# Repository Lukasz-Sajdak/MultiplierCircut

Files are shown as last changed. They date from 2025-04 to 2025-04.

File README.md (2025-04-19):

# Multiplier Circuit

## Overview
Analog multiplier circuit designed to perform multiplication of two input signals by utilizing various functional blocks working in tandem. The circuit uses customized components for efficient operation and to meet specific design requirements.

schemat

## Main Functional Blocks
The schematic is divided into the following key sections:

### Power Supply
- **Purpose:** Voltage stabilization for the circuit.
- **Components:**
  - **V+ Regulation:** The circuit uses a standard power supply for V+.
  - **V- Generation:** The negative voltage is generated using the **ICL7660AIBAZA** charge pump.

### Charge Pump
- **Purpose:** Generates the negative voltage required for specific circuit components.

### Voltage-Frequency Converter
- **Purpose:** This block, based on the **LM331**, controls and filters the input signal.
- **Adjustment:** The signal can be adjusted using an **R3 potentiometer** for finer control over the frequency.
- **Issue:** The V/F Converter isn't operating as expected due to incorrect resistor choices and insufficient current flowing into the IC.

### Adding Offset
- **Purpose:** Adds a frequency shift to the input signal, ensuring correct operation when dealing with a 0V input.
- **Components:** Implemented with the **TS912** operational amplifier.

### Subtracting Offset
- **Purpose:** Compensates for any voltage offset by subtracting a specific value.
- **Components:** The **TS912** operational amplifier is used here as well, with the offset adjusted via the **R18 potentiometer**.

### Voltage Reference
- **Purpose:** Provides a reference voltage for the circuit.
- **Component:** **TL431BIDBZR** is used for this purpose.

### Analog Switch
- **Component:** **DG419DY**  
- **Purpose:** Transfers charge based on V/F signal to perform multiplication with Vy. Connected to capacitor and output stage.

## How It Works

The circuit receives two input signals: **Vx** and **Vy**, and performs an analog multiplication of these signals.

The **Vx** signal is fed into a voltage-to-frequency converter (**V/F**, based on LM331), which converts the voltage into a frequency proportional to **Vx**. This frequency output is then used to control an analog switch.

The analog switch operates by transferring charge from the **Vy** signal to a capacitor in response to the frequency generated by the V/F converter.

**Switch connections:**
- **IN** — control signal from V/F (frequency depends on **Vx**)  
- **S2** — voltage input **Vy**  
- **D** — capacitor  
- **S1** — output  

As a result, the amount of transferred charge—and thus the output voltage—depends on both the **Vy** amplitude and the frequency determined by **Vx**. This results in **analog multiplication** of **Vx** and **Vy**.

## Known Issues
- The **V/F** is not functioning correctly due to improper resistor selection and insufficient current flow to the integrated circuit. This needs to be addressed for proper operation.

## PCB Design
The physical implementation of the circuit has been designed using **KiCad EDA 8.0.2** software.

The circuit has been **soldered and assembled**.

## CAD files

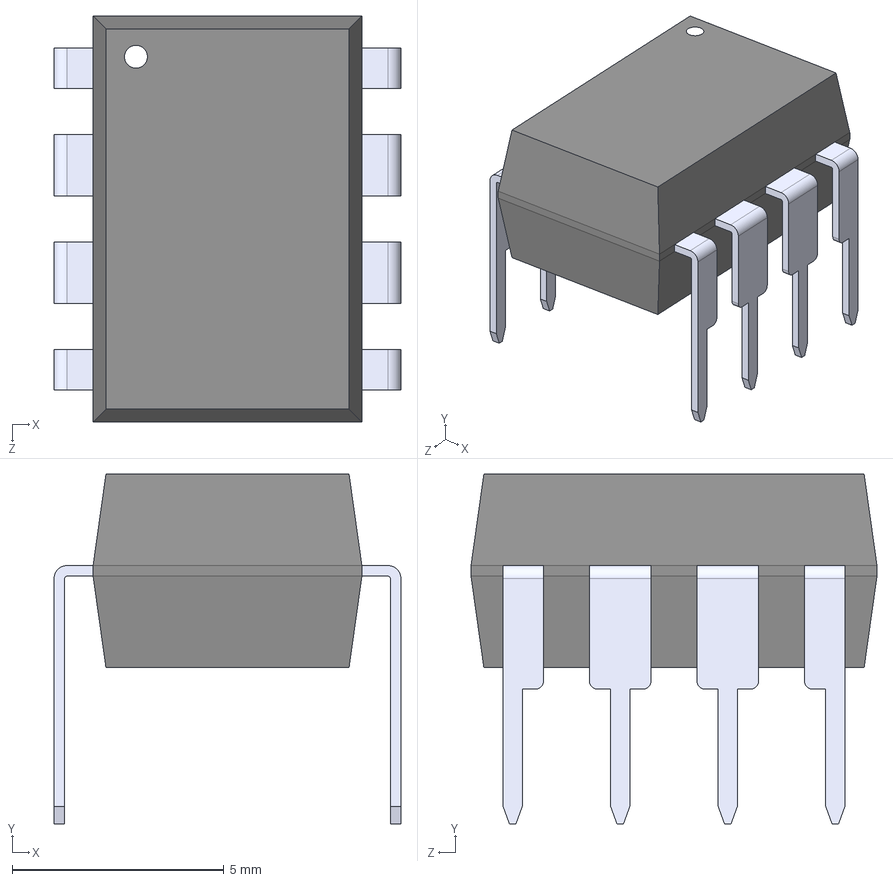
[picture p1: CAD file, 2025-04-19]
LM331N_NOPB/LM331N_NOPB.step
8.19 x 8.26 x 9.59 mm

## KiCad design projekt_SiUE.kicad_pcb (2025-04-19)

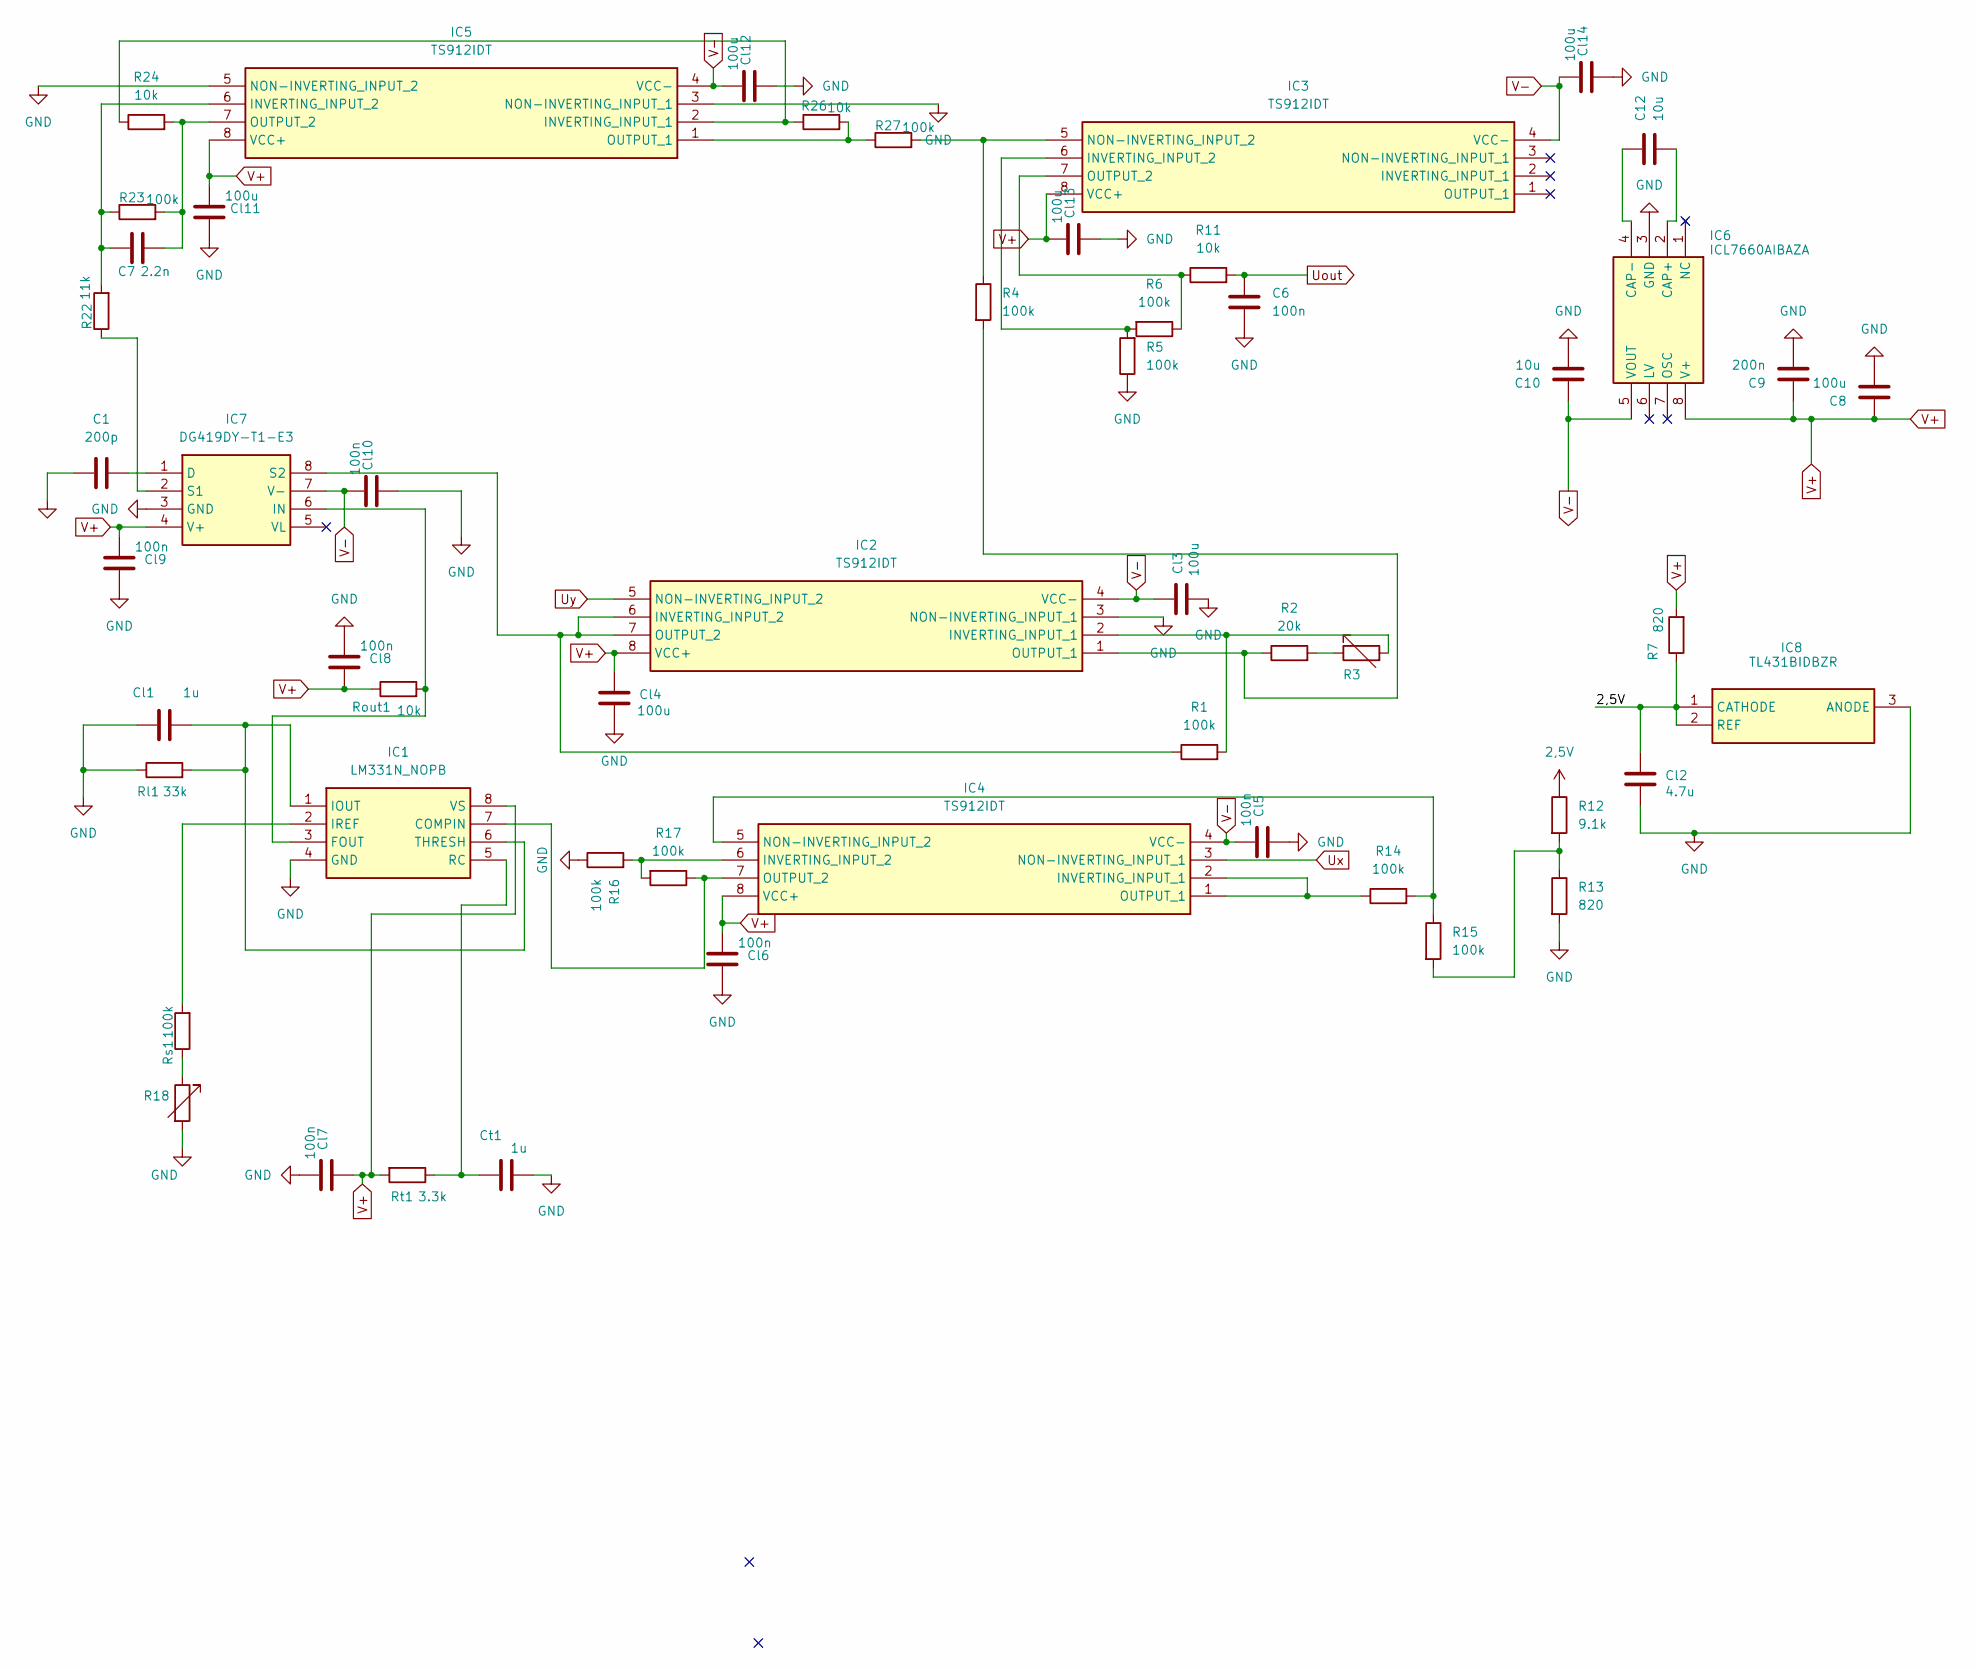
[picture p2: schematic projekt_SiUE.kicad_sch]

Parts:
C1: 200p; C_0805_2012Metric_Pad1.18x1.45mm_HandSolder
C6: 100n; C_0805_2012Metric_Pad1.18x1.45mm_HandSolder
C7: 2.2n; C_0805_2012Metric_Pad1.18x1.45mm_HandSolder
C8: 100u; CP_EIA-3528-21_Kemet-B
C9: 200n; C_0805_2012Metric_Pad1.18x1.45mm_HandSolder
C10, C12: 10u; C_0805_2012Metric_Pad1.18x1.45mm_HandSolder
Cl1: 1u; C_0805_2012Metric_Pad1.18x1.45mm_HandSolder
Cl2: 4.7u; C_0805_2012Metric_Pad1.18x1.45mm_HandSolder
Cl3, Cl4, Cl11, Cl12, Cl13, Cl14: 100u; C_0805_2012Metric_Pad1.18x1.45mm_HandSolder
Cl5: 100n; CP_EIA-3528-21_Kemet-B
Cl6, Cl7, Cl8, Cl9, Cl10: 100n; C_0805_2012Metric_Pad1.18x1.45mm_HandSolder
Ct1: 1u; C_0805_2012Metric_Pad1.18x1.45mm_HandSolder
IC1: LM331N_NOPB; DIP794W53P254L959H508Q8N; Manufacturer_Part_Number LM331N/NOPB
IC2, IC3, IC4, IC5: TS912IDT; SOIC127P600X175-8N; Manufacturer_Part_Number TS912IDT
IC6: ICL7660AIBAZA; SOIC127P600X175-8N; Manufacturer_Part_Number ICL7660AIBAZA
IC7: DG419DY-T1-E3; SOIC127P600X175-8N; Manufacturer_Part_Number DG419DY-T1-E3
IC8: TL431BIDBZR; SOT95P237X112-3N; Manufacturer_Part_Number TL431BIDBZR
R1, R4, R5, R6, R14, R15, R16, R17, R23, R27: 100k; R_0805_2012Metric_Pad1.20x1.40mm_HandSolder
R2: 20k; R_0805_2012Metric_Pad1.20x1.40mm_HandSolder
R3, R18: R_Variable; Potentiometer_ACP_CA6-VSMD_Vertical
R7, R13: 820; R_0805_2012Metric_Pad1.20x1.40mm_HandSolder
R11, R24, R26: 10k; R_0805_2012Metric_Pad1.20x1.40mm_HandSolder
R12: 9.1k; R_0805_2012Metric_Pad1.20x1.40mm_HandSolder
R22: 11k; R_0805_2012Metric_Pad1.20x1.40mm_HandSolder
Rl1: 33k; R_0805_2012Metric_Pad1.20x1.40mm_HandSolder
Rout1: 10k; R_0805_2012Metric_Pad1.20x1.40mm_HandSolder
Rs1: 100k; R_0805_2012Metric_Pad1.20x1.40mm_HandSolder
Rt1: 3.3k; R_0805_2012Metric_Pad1.20x1.40mm_HandSolder

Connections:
2,5V: Cl2.2, IC8.1 (CATHODE), IC8.2 (REF), R7.1, R12.1
GND: C1.1, C6.2, C8.2, C9.1, C10.1, Cl1.2, Cl2.1, Cl3.1, Cl4.1, Cl5.1, Cl6.1, Cl7.2, Cl8.2, Cl9.1, Cl10.1, Cl11.1, Cl12.1, Cl13.1, Cl14.1, Ct1.1, IC1.4 (GND), IC2.3 (NON-INVERTING_INPUT_1), IC5.3 (NON-INVERTING_INPUT_1), IC5.5 (NON-INVERTING_INPUT_2), IC6.3 (GND), IC7.3 (GND), IC8.3 (ANODE), R5.1, R13.2, R16.1, R18.2, Rl1.1
unnamed: IC1.7 (COMPIN), IC4.7 (OUTPUT_2), R17.1
unnamed: IC1.3 (FOUT), IC7.6 (IN), Rout1.2
unnamed: Cl1.1, IC1.1 (IOUT), IC1.6 (THRESH), Rl1.2
unnamed: IC1.2 (IREF), Rs1.2
unnamed: Ct1.2, IC1.5 (RC), Rt1.1
unnamed: IC2.2 (INVERTING_INPUT_1), R1.2, R3.2
unnamed: IC2.6 (INVERTING_INPUT_2), IC2.7 (OUTPUT_2), IC7.8 (S2), R1.1
unnamed: IC2.1 (OUTPUT_1), R2.1, R4.2
unnamed: IC3.6 (INVERTING_INPUT_2), R5.2, R6.2
unnamed: IC3.5 (NON-INVERTING_INPUT_2), R4.1, R27.2
unnamed: IC3.7 (OUTPUT_2), R6.1, R11.1
unnamed: IC4.1 (OUTPUT_1), IC4.2 (INVERTING_INPUT_1), R14.1
unnamed: IC4.6 (INVERTING_INPUT_2), R16.2, R17.2
unnamed: IC4.5 (NON-INVERTING_INPUT_2), R14.2, R15.1
unnamed: IC5.2 (INVERTING_INPUT_1), R24.1, R26.1
unnamed: C7.1, IC5.6 (INVERTING_INPUT_2), R22.2, R23.1
unnamed: IC5.1 (OUTPUT_1), R26.2, R27.1
unnamed: C7.2, IC5.7 (OUTPUT_2), R23.2, R24.2
unnamed: C12.1, IC6.2 (CAP+)
unnamed: C12.2, IC6.4 (CAP-)
unnamed: C1.2, IC7.1 (D)
unnamed: IC7.2 (S1), R22.1
unnamed: R2.2, R3.1
unnamed: R12.2, R13.1, R15.2
unnamed: R18.1, Rs1.1
Uout: C6.1, R11.2
Ux: IC4.3 (NON-INVERTING_INPUT_1)
Uy: IC2.5 (NON-INVERTING_INPUT_2)
V+: C8.1, C9.2, Cl4.2, Cl6.2, Cl7.1, Cl8.1, Cl9.2, Cl11.2, Cl13.2, IC1.8 (VS), IC2.8 (VCC+), IC3.8 (VCC+), IC4.8 (VCC+), IC5.8 (VCC+), IC6.8 (V+), IC7.4 (V+), R7.2, Rout1.1, Rt1.2
V-: C10.2, Cl3.2, Cl5.2, Cl10.2, Cl12.2, Cl14.2, IC2.4 (VCC-), IC3.4 (VCC-), IC4.4 (VCC-), IC5.4 (VCC-), IC6.5 (VOUT), IC7.7 (V-)

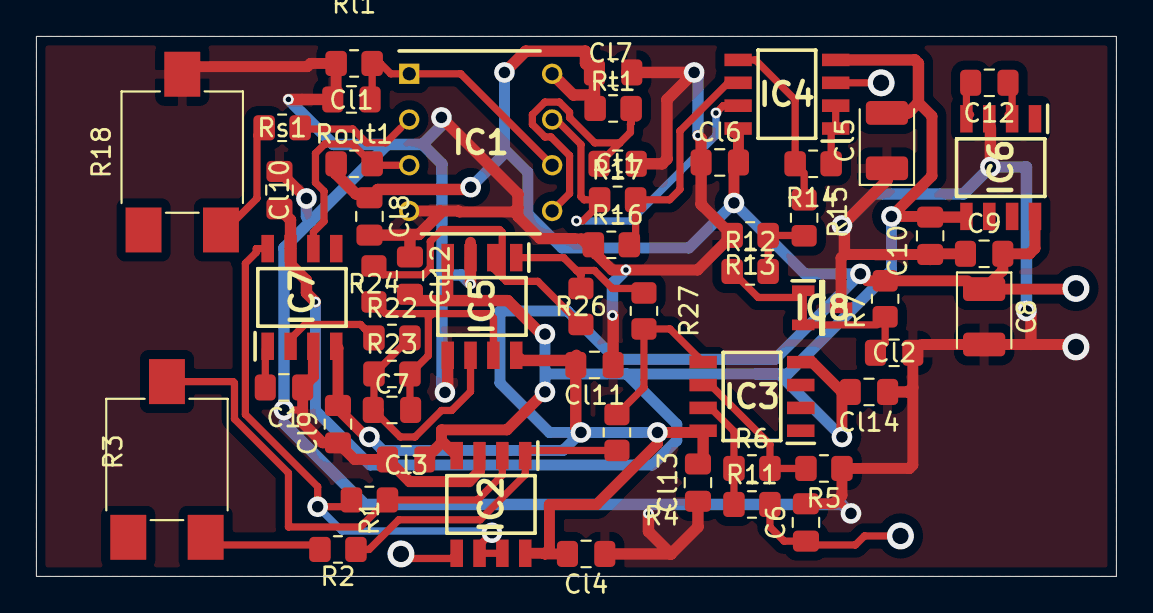
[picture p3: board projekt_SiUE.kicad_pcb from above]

Board: 2 copper layers, 60.0 x 30.0 mm, 54 parts (0 on the bottom side), 30 nets.
